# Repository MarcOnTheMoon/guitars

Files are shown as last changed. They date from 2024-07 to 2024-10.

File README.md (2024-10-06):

# Hexaphonic Guitar and Signal Analysis

> [!IMPORTANT]
> This repository is __work-in-progress__ of student theses.<br>
> It is subject to change, __not__ a reviewed publication of final results.

## What's it about?
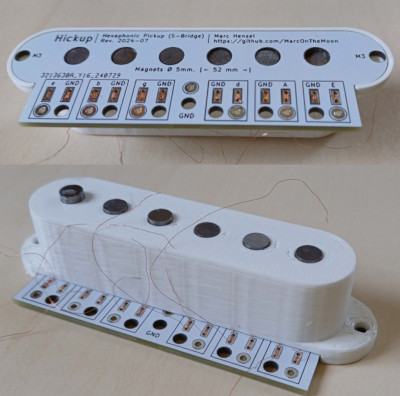
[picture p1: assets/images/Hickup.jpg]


Pickups of electric guitars typically consist of a single coil that translates oscillating movements of the strings into voltage. One electrical signal for all simultaneously played tones results. In contrast, some types of __hexaphonic pickups__ have a dedicated coil for each of the guitar's strings. Consequently, when applying pitch detection methods, one can identify which tone is played and on _which string_ it is played. Pretty cool, isn't it?

But why do we want to have a single signal for each string? Well, there are several advantages in that. Splitting the single polyphonic signal of a common pickup into six monophonic signals of a hexaphonic pickup simplifies pitch detection. So far, so boring. However, it is also the first step to automatically generate so-called tab notation while playing.

In this context, we did a first Master thesis with the objective to create a basic audio processing chain consisting of building our own hexaphonic pickup, pitch detection, and conversion into the MIDI file format. While being successful, there were too many aspects to cover, hence, the thesis could only be a proof of concept. Now comes the long and hard work of doing things "right".

Feel free to join us on this journey ... starting with the pickup. (What else?)
<br clear=all>

## Hexaphonic pickup

> [!NOTE]
> These days (October 2024) I build the next version of a largely improved pickup.<br>
> A detailed report on the design and production is in preparation and will follow soon.

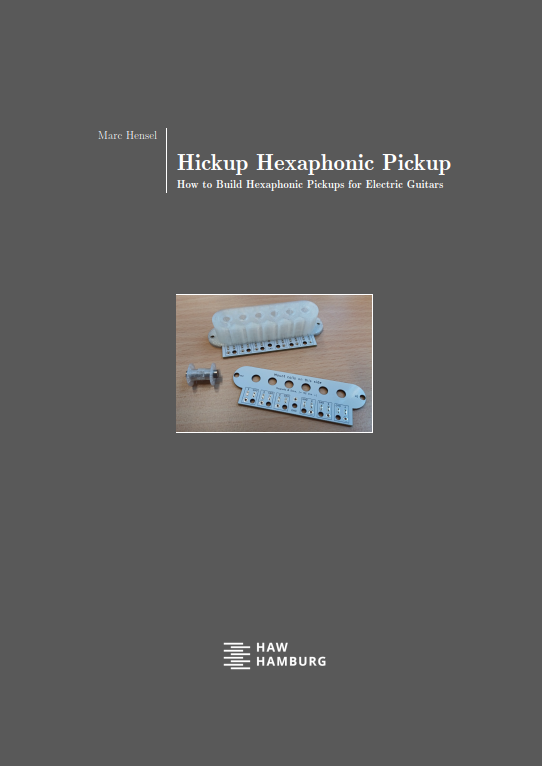
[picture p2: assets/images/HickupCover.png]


The thesis succeeded in building a hexaphonic pickup, however, this has been extremely cumbersome and the resulting pickup was mechanically instable. Meanwhile, I have developed a significantly better design and production process based on the valuable insights we got from the first try.

Amongst others, I have improved the housing, designed a custom PCB as mechanically and electrical stable cover, and I have developed a device controlled by a Python application for winding the coils. The pickup's dimensions correspond to single coil pickup mounted at the guitar bridge. Each of the six coils hat about 2,000 windings of copper wire (0.08 mm diameter with isolation), and an electrical resistance of about 170 Ohm. I use a 7-core XLR cable, which is split into 6 standard instrument cables in a dedicated adapter box. The cables connect to an USB audio interface.

As stated above, I am already preparing a detailed report on the design as well as the production process. Material such as 3D print files and the source code of the pickup winding device are available in this repository.
<br clear=all>

## Achievements so far
In a first Master thesis, Fiona Vogel managed to record samples with her own hexaphonic pickup, apply pitch detection based on the YIN algorithm, and write the result as multi-track MIDI file. Since then, the improved design of the pickup has made significant progress.

- [X] _Hardware_: design of a hexaphonic pickup (including coil winding machine, 3D prints, and PCB)
- [X] _Signal chain_: simple chain from hexaphonic guitar to signal analysis in a laptop
- [X] _Pitch detection_: proof of concept for MIDI conversion of guitar signals

## Next steps
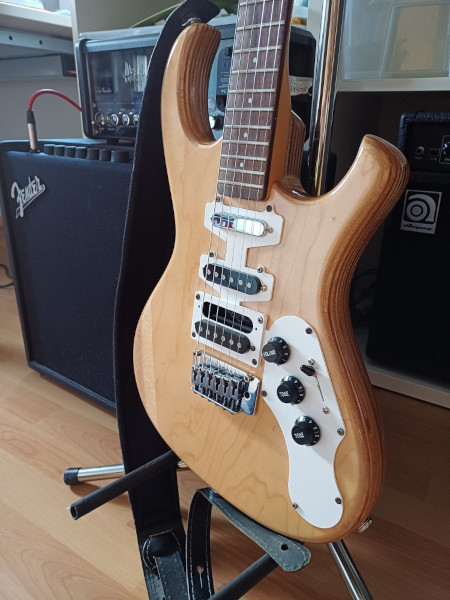
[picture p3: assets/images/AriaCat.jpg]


With our own hexaphonic pickups available, we have a good foundation for lots and lots of ideas to work on in detail. The next step is to finalize two pickups and mount these in our guitars. Future student topics include, in particular, audio signal analysis using neural networks and signal processing methods, transcription to tab notation, MIDI guitar, and live playing with low latency.

In case you are interested, I have a simple guitar from university available for my students and a private guitar for myself. I wouldn't replace any pickup of my beloved Fender Telecaster, however, I have completely renovated my old Aria Pro II Cat Series that I played in my prior life as musician. I have removed the varnish by hand (think twice before you do that!), applied transparent varnish, replaced all electric components, replaced the pickguard by own 3D-printed parts, and such. Most important, I have freed up the Humbucker slot at the bridge, which gives me plenty of space for our custom pickups.
<br clear=all>

## Uploaded material
- [X] Reports (Building the pickup, [Thesis poster](docs/reports))
- [X] Pickup housing and coils ([3D print files](hexaphonic_pickup/hardware/3d_print_files/pickup))
- [X] Coil winding device ([3D print files](hexaphonic_pickup/hardware/3d_print_files/winder), [source code](hexaphonic_pickup/src/winder))

## Contributors
The activities done so far and hopefully still to come are collaborations of myself and my magnificent students of our [Department at HAW Hamburg](https://www.haw-hamburg.de/hochschule/technik-und-informatik/departments/informations-und-elektrotechnik/studium/studiengaenge/):

- Marc Hensel (design of hexaphonic pickup and coil winder)
- Fiona Vogel (theses: hexaphonic guitar, MIDI)

## Supporters
My deepest thanks go to [No.1 Guitar Center, Hamburg](https://www.no1-guitars.de/). Sharing the same passion for music, they did not hesitate to support our work not only by kind words, but also by providing an USB audio interface offering inputs to the six coils of our hexaphonic pickups. Without this valuable support, we could not have done our work as intended.

## Contact
[Marc Hensel](http://www.haw-hamburg.de/marc-hensel), University of Applied Sciences Hamburg (HAW Hamburg)

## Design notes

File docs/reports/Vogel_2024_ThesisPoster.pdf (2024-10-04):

## Bau eines hexaphonischen Tonabnehmers und Konvertierung analoger Töne von E-Gitarren in das MIDI-Format

### Masterarbeit Fiona Vogel Prof. Dr.-Ing. Marc Hensel und Prof. Dr.-Ing. Sönke Appel

Hochschule fur Angewandte Wissenschaften Hamburg ¨ | · Fachhochschule Westkuste ¨

Tonabnehmer elektrischer Gitarren bestehen aus einer einzelnen Spule, welche Schwingungen der Saiten in einem Magnetfeld mittels Induktion in Spannung wandelt. Es resultiert ein gemeinsames elektrisches Signal fu¨r alle zeitgleich gespielten Töne. Hexaphonische Tonabnehmer nehmen hingegen jede Saite mit einer eigenen Spule ab. Durch Methoden der Tonhöhenerkennung können daher die gespielten Töne sowohl bestimmt als auch den entsprechenden Saiten zugeordnet werden. Die Aufteilung des polyphonen in sechs monophone Signale vereinfacht die Analyse und ist zugleich eine Vorbedingung zur automatischen Notentranskription in sogenannte Tabulatur.
Ziel dieser Arbeit ist eine erste Verarbeitungskette bestehend aus einem eigenen Tonabnehmer, Analyse der gespielten Tonhöhen und Konvertierung in das in der Musik verbreitete MIDI-Format (Abb. 1). Nachfolgend wird zudem der Stand der weiteren Entwicklung dargestellt sowie ein Ausblick auf mögliche weitere Abschlussarbeiten gegeben.

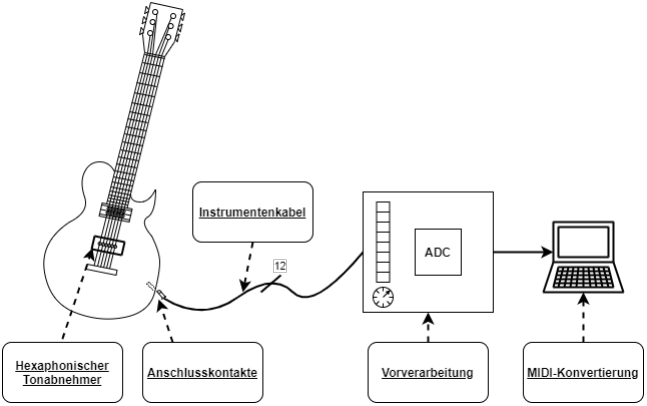
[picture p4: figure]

Abbildung 1: Verarbeitungskette

Hexaphonischer Tonabnehmer

Abbildung 2

Fu¨r den Tonabnehmer wurde ein Gehäuse mit sechs Aussparungen fu¨r Spulen modelliert und in 3D-Druck gefertigt. Die Spulen wurden aus 0,08 mm dickem Kupferlackdraht um auf einem Schrittmotor stehende Magneten gewickelt, mit Wachs im Gehäuse eingegossen und u¨ber eine Lochrasterplatine elektrisch verbunden. Nach Montage in der Gitarre wurden die Saiten u¨ber eigene Eingänge eines Audio-Interface zur Weiterverarbeitung im Laptop aufgenommen.

Analyse der Tonhöhen und MIDI-Konvertierung

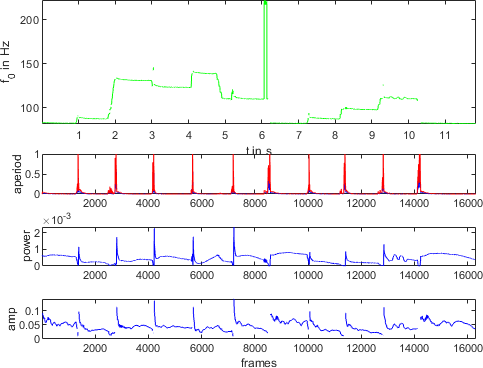
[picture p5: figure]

Abbildung 3: Tonhöhen-Analyse

Zur Bestimmung der Tonhöhen
und Konvertierung in MIDI wurden die mehrkanaligen Aufnahmen zunächst in Audio-Dateien gespeichert. Die anschließende Verarbeitung wurde in Octave umgesetzt. Sie besteht aus der unabhängigen Analyse der Tonspuren aller Saiten
auf Basis des YIN-Algorithmus sowie der Speicherung der erkannten
Töne in einer MIDI-Datei mit jeweils eigener Tonspur pro Saite.

Verbesserter Tonabnehmer (M. Hensel)

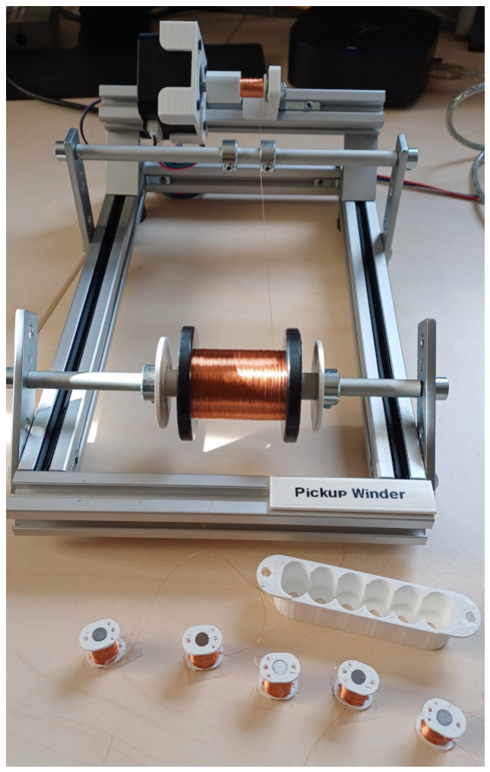
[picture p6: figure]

Abbildung 4: Spulen

Die Fertigung des Tonabnehmers hat sich als ausgesprochen muḧsam, das Resultat als mechanisch instabil erwiesen. Daher wurden inzwischen sowohl das Design als auch der Fertigungsprozess unter Beru¨cksichtigung der gewonnenen Erkenntnisse erheblich verbessert.
Unter anderem wurde das Gehäuse u¨berarbeitet, ein u¨ber eine Python-Anwendung gesteuertes Gerät zum Wickeln der Spulen sowie eine Platine als elektrisch und mechanisch stabiler Abschluss des Gehäuses entwickelt. Die Abmessungen der gefertigten Tonabnehmer entsprechen einem Single
Coil-Format in Bridge-Position. Die Spulen
enthalten jeweils etwa 2.000 Windungen und besitzen einen elektrischen Widerstand von etwa 170 Ω. Der Anschluss an die Gitarre erfolgt u¨ber ein 7-poliges XLR-Kabel, welches vor dem Audio-Interface u¨ber eine Adapter-Box auf sechs Instrumentenkabel aufgeteilt wird.

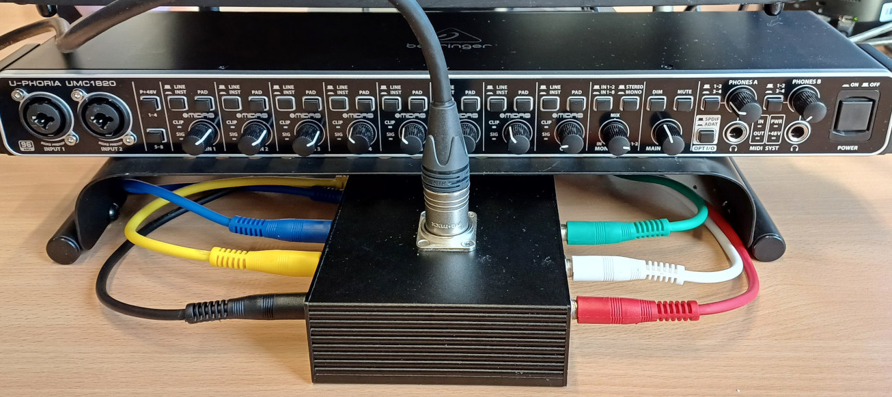
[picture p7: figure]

(a) Tonabnehmer | (b) Adapter-Box

Abbildung 5: Verbesserter Tonabnehmer und Adapter-Box

Themen fur weitere Arbeiten ¨

Potenzielle Folgearbeiten in der Audiotechnik beinhalten beispielsweise: Ton-Analyse mittels neuronaler Netze
Ton-Analyse mittels Methoden der Signalverarbeitung
Transkription in Tabulatur und weitere Anwendungen
Live-Spiel mit geringer Latenz
Entwicklung eines USB-Audio-Interfaces (Hard- und Software)

Offentliche Dateien im Internet ¨

3D-Druckdateien, Quelltexte usw. werden nach und nach auf der verlinkten Seite öffentlich zur Verfu¨gung gestellt.

Förderer

Wir danken No.1 Guitar Center GmbH, Hamburg, fu¨r das zur Verfu¨gung gestellte Audio-Interface und die damit verbundene Unterstuẗzung unserer Arbeit.

Stand: 30.09.2024

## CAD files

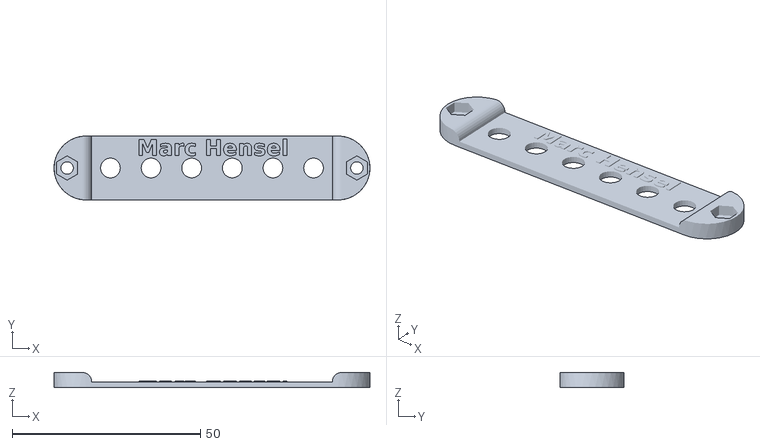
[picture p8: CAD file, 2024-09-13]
hexaphonic_pickup/hardware/3d_print_files/pickup/height 18 mm/HexPickup_Housing_Bottom.stl
84.0 x 17.0 x 4.00

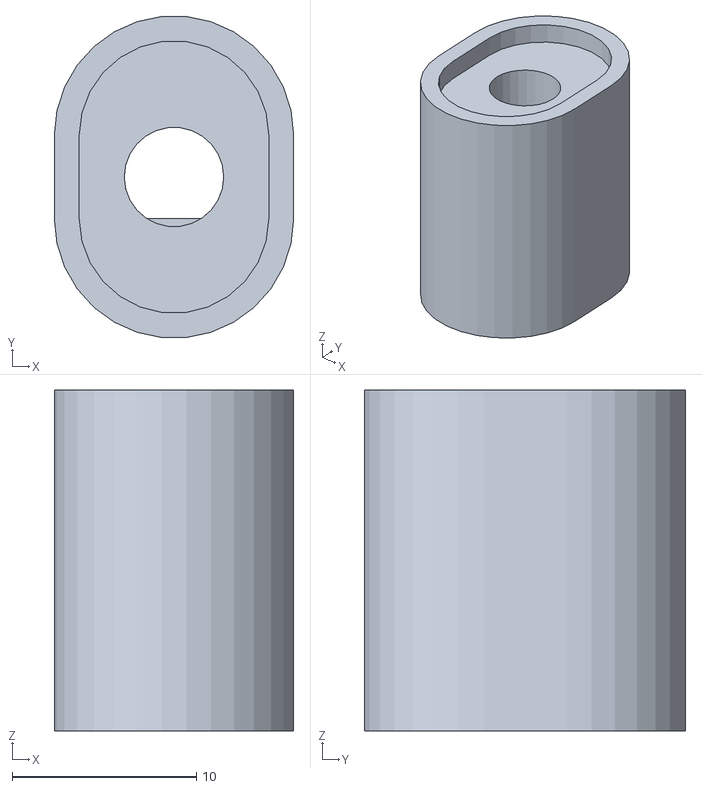
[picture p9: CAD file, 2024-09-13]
hexaphonic_pickup/hardware/3d_print_files/winder/CoilHolder-MotorTip-18.5mm-5mm.stl
13.0 x 17.4 x 18.5

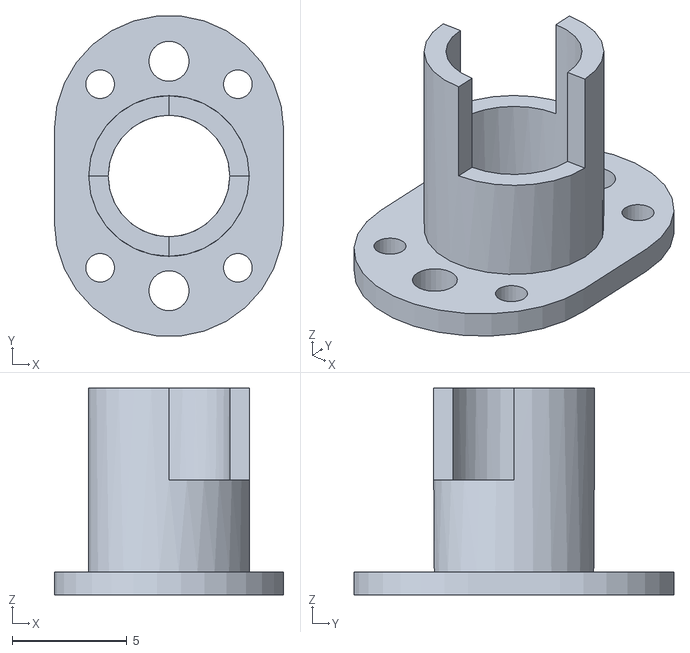
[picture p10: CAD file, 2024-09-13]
hexaphonic_pickup/hardware/3d_print_files/pickup/height 18 mm/HexPickup_Coil-14x5mm.stl
10.0 x 13.9 x 9.00

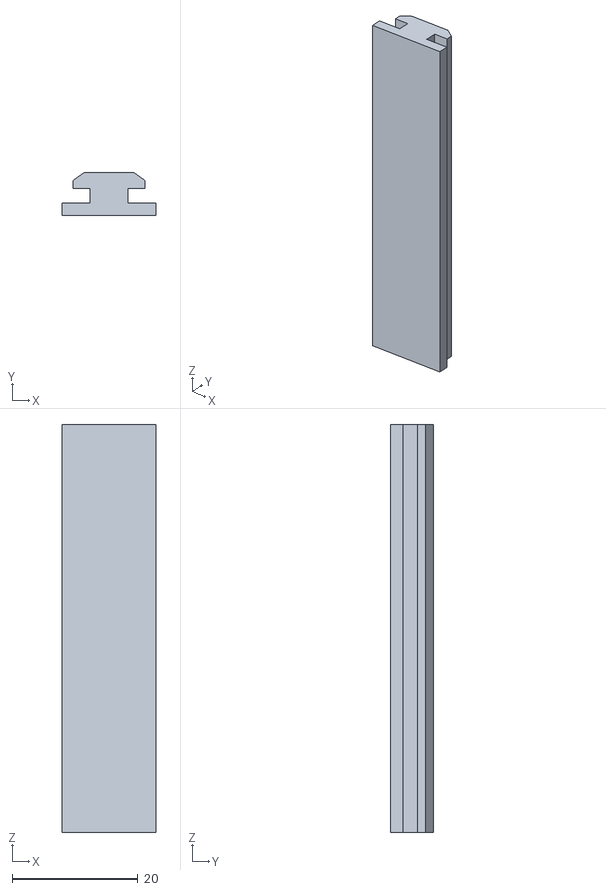
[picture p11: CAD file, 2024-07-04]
hexaphonic_pickup/hardware/3d_print_files/winder/Profile-20x20_Label-65x15mm.stl
15.0 x 6.80 x 65.0

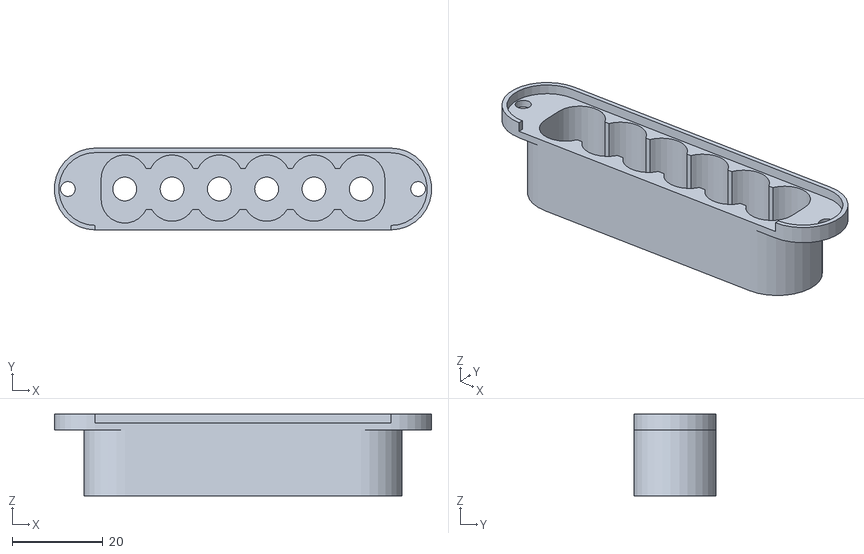
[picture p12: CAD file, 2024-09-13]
hexaphonic_pickup/hardware/3d_print_files/pickup/height 18 mm/HexPickup_Housing-70x18x18mm.stl
82.9 x 18.0 x 18.0

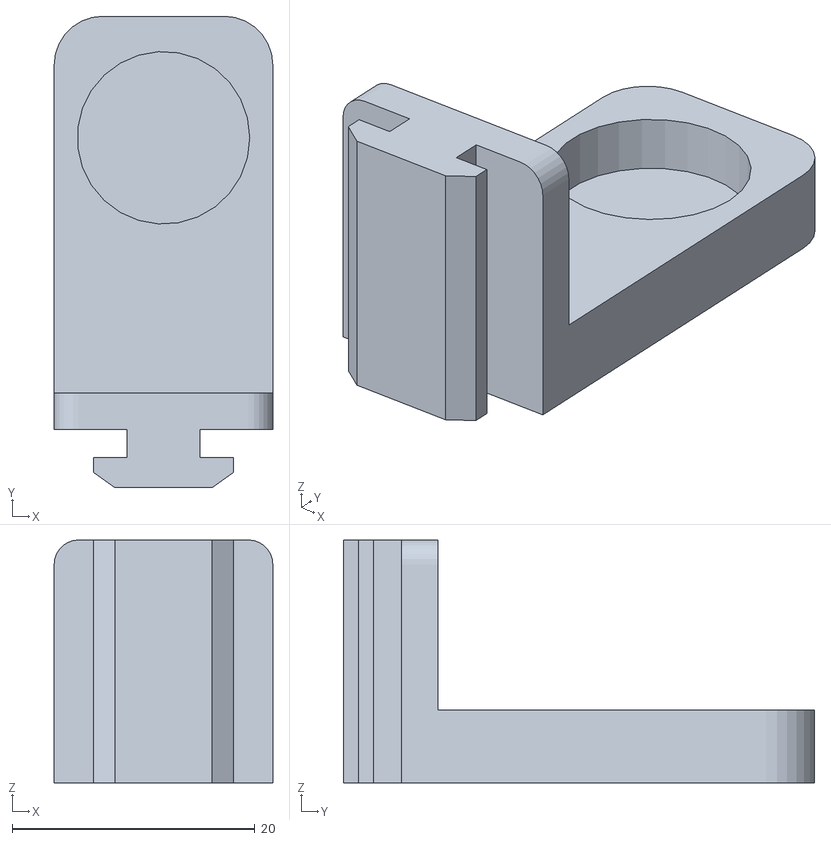
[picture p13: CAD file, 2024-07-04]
hexaphonic_pickup/hardware/3d_print_files/winder/CoilHolder-BallBearing-14x4mm.stl
18.0 x 38.8 x 20.0

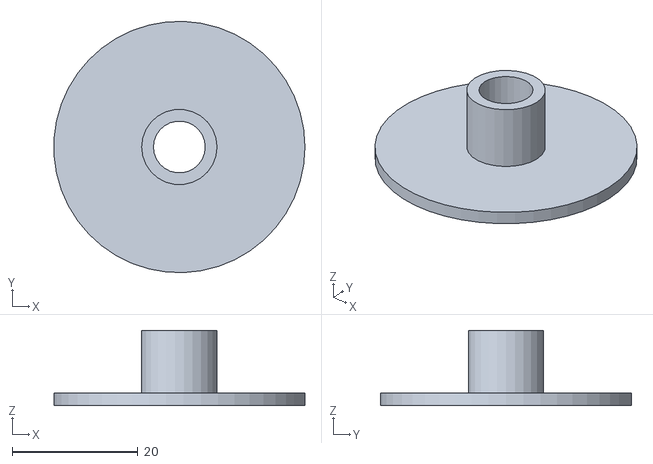
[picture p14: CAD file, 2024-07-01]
hexaphonic_pickup/hardware/3d_print_files/winder/SpoolGuidance-40mm-8mm.stl
40.0 x 40.0 x 12.0

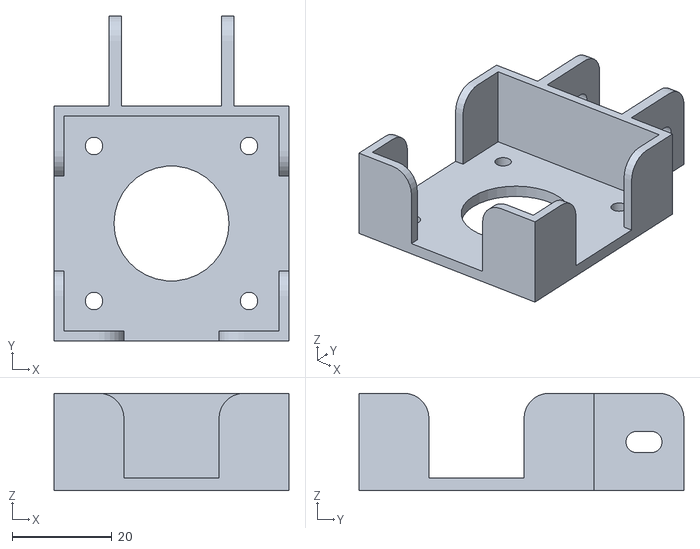
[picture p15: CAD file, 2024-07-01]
hexaphonic_pickup/hardware/3d_print_files/winder/Nema17_OnProfileMount-M4.stl
47.0 x 65.0 x 19.5

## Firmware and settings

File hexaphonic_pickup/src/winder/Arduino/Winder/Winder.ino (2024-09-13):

/*****************************************************************************************************
 * Hexaphonic pickup winder machine
 *****************************************************************************************************
 * Author: Marc Hensel, http://www.haw-hamburg.de/marc-hensel
 * Project: https://github.com/MarcOnTheMoon/guitars
 * Copyright: 2024, Marc Hensel
 * Version: 2024.09.13
 * License: CC BY-NC-SA 4.0, see https://creativecommons.org/licenses/by-nc-sa/4.0/deed.en
 *****************************************************************************************************
 * Board:
 * - Arduino Uno R3
 * 
 * Modules:
 * - None
 *****************************************************************************************************/

#include "SerialCom.h"
#include "StepperMotor.h"

/*****************************************************************************************************
 * Constants
 *****************************************************************************************************/

// Stepper motor
#define STEPPER_ENA_PIN 2
#define STEPPER_DIR_PIN 3
#define STEPPER_PUL_PIN 4
#define STEPS_PER_REVOLUTION 200  // 360° / (1.8° per step) = 200 steps

// Commands in communication with Python script
#define ENABLE_STEPPER        'E'   // Set "Enable" of motor driver to hight
#define DISABLE_STEPPER       'e'   // Set "Enable" of motor driver to low
#define DIR_CLOCKWISE         'D'   // Set "Direction" of motor driver to clockwise
#define DIR_COUNTER_CLOCKWISE 'd'   // Set "Direction" of motor driver to counter-clockwise
#define SET_SPEED_RPS         'S'   // Set motor speed (rotations per second send as next unsigned char)
#define GET_REV_COUNT         'C'   // Get count of full revolutions the motor has moved
#define RESET_REV_COUNT       'R'   // Reset counter of full revolutions the motor has moved
#define SEND_OK               '>'   // Request acqknowledge

/*****************************************************************************************************
 * Global variables
 *****************************************************************************************************/

// Serial communication (e.g., with Python script on connected Laptop)
SerialCom serialCom(Serial);

// Stepper motor (set to "not enabled" in driver's constructor)
StepperMotor motor(STEPPER_ENA_PIN, STEPPER_DIR_PIN, STEPPER_PUL_PIN, STEPS_PER_REVOLUTION);
unsigned long stepCount = 0;

/*****************************************************************************************************
 * Standard methods
 *****************************************************************************************************/

/**! Initialize program.
 * 
 * - The stepper motor is initialized with status "not enabled" as global variable.
 * - Serial communication using Arduino's "Serial" object is done using the global variable "serialCom".
 */
void setup() {
  // USB connection to Python script
  Serial.begin(38400);       // Make sure baud rate matches Python script
}

/* --------------------------------------------------------------------------------------------------*/

/**! Main loop. */
void loop() {
  // Receive and process commands
  while (serialCom.hasNext()) {
    processCommand(serialCom.getNext());
  }

  // Move stepper motor
  if (motor.getEnabled())
    stepCount += motor.moveSteps(10);
}

/*****************************************************************************************************
 * Receive and process commands
 *****************************************************************************************************/

/**! Process commands received via "serialCom".
 * 
 * @param command [in] Command (see Commands.h for mapping)
 */
void processCommand(char command) {
  switch (command) {
    // Get or restet count of full revolutions the motor has done
    case GET_REV_COUNT:
      Serial.println((unsigned long)(stepCount / STEPS_PER_REVOLUTION));
      break;
    case RESET_REV_COUNT:
      stepCount = 0;
      break;

    // Set enabled pin of stepper driver
    case ENABLE_STEPPER:
      motor.setEnabled(true);
      break;
    case DISABLE_STEPPER:
      motor.setEnabled(false);
      break;

    // Set stepper turning direction
    case DIR_CLOCKWISE:
      motor.setDirection(MotorDirection::CLOCKWISE);
      break;
    case DIR_COUNTER_CLOCKWISE:
      motor.setDirection(MotorDirection::COUNTER_CLOCKWISE);
      break;
      
    // Set stepper motor speed
    case SET_SPEED_RPS:
      motor.setTargetSpeed(serialReceiveNextValue());
      break;

    // Send acqknowledge
    case SEND_OK:
      Serial.println("ok");
      break;
  }
}

/* --------------------------------------------------------------------------------------------------*/

/**! Wait for and get next value sent over serial communication.
 * 
 * @return Next received value
 */
int serialReceiveNextValue(void) {
  // Wait for next sent byte
  while (serialCom.hasNext() == false) {
    // NOP
  }

  return (int)serialCom.getNext();
}

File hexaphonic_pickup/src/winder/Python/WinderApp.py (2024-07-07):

"""
Control app for a hexaphonic pickup winder.

@author: Marc Hensel
@contact: http://www.haw-hamburg.de/marc-hensel
@copyright: 2024
@version: 2024.07.07
@license: CC BY-NC-SA 4.0, see https://creativecommons.org/licenses/by-nc-sa/4.0/deed.en
"""
import time
import threading
from ArduinoCOM import ArduinoCOM
from WinderGUI import WinderGUI

class WinderApp():

    # =========================================================================
    # ========== Class constants ==============================================
    # =========================================================================

    # Command chars expected by the Arduino
    _commands = {
        'enableMotor':          'E',    # 'Enable' signal high
        'disableMotor':         'e',    # 'Enable' signal low
        'dirClockwise':         'D',    # Direction clockwise
        'dirCounterClockwise':  'd',    # Direction counter-clockwise
        'setSpeedRevsPerSec':   'S',
        'getRevCount':          'C',
        'resetRevCounter':      'R',
        'sendOk':               '>'
    }

    # =========================================================================
    # ========== Constructor ==================================================
    # =========================================================================

    def __init__(self, serialCOM=None):
        """
        Constructor.
        
        The contructor tries to connect to an Arduino using serial COM ports.
        If connection succeeds, it generates and runs the GUI.
        
        Parameters
        ----------
        serialCOM : int, optional
            Serial port Arduino is connected to (e.g., '3' for 'COM3').
            Tries to connect to ports 0 to 15, if argument is None. (Default: None)

        Returns
        -------
        None.

        """
        # Connect to Arduino (will reset Arduino => Runs setup())
        self.__threadLock = threading.Lock()
        self.__arduino = ArduinoCOM(serialCOM=serialCOM, baudRate=38_400)

        # Create and start GUI
        self.__gui = WinderGUI(parentApp=self)

    # =========================================================================
    # ========== Serial connection ============================================
    # =========================================================================

    def close(self, waitTimeSec=2.0):
        """
        Requests Arduino to stop and disable stepper motor and closes serial connection.

        Parameters
        ----------
        waitTimeSec : float
            Delay before stopping and disabling stepper [s] (Default: 2.0)

        Returns
        -------
        None.

        """
        time.sleep(waitTimeSec)
        print('\nClosing connection:')
        self.setSpeed(revsPerSec=0)
        self.enableMotor(False)
        time.sleep(1.0)             # Wait for Arduino to read buffer
        self.__arduino.close()

    # -------------------------------------------------------------------------

    def __sendWithReply(self, command, isRequestAck=True):
        """
        Send command to Arduino requesting and waiting for reply.

        Parameters
        ----------
        command : string
            Command string to send (typically chars from dictionary _command).

        Returns
        -------
        string
            Reply send by the Arduino (typically 'ok' when requesting ACK).

        """
        # Send command (and request for acknowledgement)
        if isRequestAck == True:
            self.__arduino.writeString(command + self._commands['sendOk'])
        else:
            self.__arduino.writeString(command)
            
        # Receive and return reply
        return self.__arduino.readLine()

    # =========================================================================
    # ========== Motor control ================================================
    # =========================================================================

    def enableMotor(self, isEnabled):
        """
        Enable or disable stepper motor.
        
        If the motor is enabled, current is flowing through it and it actively
        holds its position. When disabled, one can easily move the motor by
        hand.

        Parameters
        ----------
        isEnabled : boolean
            Enable stepper if True, else disable stepper.

        Returns
        -------
        None.

        """
        self.__threadLock.acquire()

        # Determine command
        if isEnabled:
            print('Enable motor', end=' ')
            command = self._commands['enableMotor']
        else:
            print('Disable motor', end=' ')
            command = self._commands['disableMotor']

        # Send command and print reply
        reply = self.__sendWithReply(command)
        print('... ' + reply)            
        self.__threadLock.release()

    # -------------------------------------------------------------------------

    def setDirection(self, isClockwise):
        """
        Set the turning direction of the stepper motor.

        Parameters
        ----------
        isClockwise : boolean
            Turn steppr clockwise if True, else counter-clockwise.

        Returns
        -------
        None.

        """
        self.__threadLock.acquire()

        # Determine command
        if isClockwise:
            print('Turn clockwise', end=' ')
            command = self._commands['dirClockwise']
        else:
            print('Turn counter-clockwise', end=' ')
            command = self._commands['dirCounterClockwise']

        # Send command and print reply
        reply = self.__sendWithReply(command)
        print('... ' + reply)            
        self.__threadLock.release()

    # -------------------------------------------------------------------------
    
    def setSpeed(self, revsPerSec):
        """ Set stepper motor speed.
        
        Parameters
        ----------
        revsPerSec : int
            Motor speed [revolutions/sec].

        Returns
        -------
        None.

        """
        self.__threadLock.acquire()

        # Command + value
        print('Set speed [rps]: {}'.format(revsPerSec), end=' ')
        command = self._commands['setSpeedRevsPerSec']
        command += chr(revsPerSec)

        # Send command and print reply
        reply = self.__sendWithReply(command)
        print('... ' + reply)
        self.__threadLock.release()

    # =========================================================================
    # ========== Revolution counter ===========================================
    # =========================================================================

    def getRevCount(self):
        """ Get count of motor full revolutions from Arduino.
        
        Warning: Querying the rev count leads to a small pause in turning the
        stepper motor at the Arduino side. To run the stepper smoothly, do not
        use the query.
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

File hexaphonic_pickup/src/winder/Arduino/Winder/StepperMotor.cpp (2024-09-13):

/*****************************************************************************************************
 * Control stepper motor
 *****************************************************************************************************
 * Author: Marc Hensel, http://www.haw-hamburg.de/marc-hensel
 * Project: https://github.com/MarcOnTheMoon/guitars
 * Copyright: 2024, Marc Hensel
 * Version: 2024.09.13
 * License: CC BY-NC-SA 4.0, see https://creativecommons.org/licenses/by-nc-sa/4.0/deed.en
 *****************************************************************************************************/

#include "StepperMotor.h"
#include <Arduino.h>

/*****************************************************************************************************
 * Constructor
 *****************************************************************************************************/

/**! Initialize object.
 * 
 * @param enablePin [in] Arduino port connecting to motor driver's "Enable"
 * @param dirPin [in] Arduino port connecting to motor driver's "Direction"
 * @param pulsePin [in] Arduino port connecting to motor driver's "Pulse"
 */
StepperMotor::StepperMotor(int enablePin, int dirPin, int pulsePin,int stepsPerRevolution)
  : driver(enablePin, dirPin, pulsePin), STEPS_PER_REV(stepsPerRevolution) {
}

/*****************************************************************************************************
 * Getter
 *****************************************************************************************************/

/**! Get status of driver's enable port.
 * 
 * @return True if motor is enabled, else false.
 */
bool StepperMotor::getEnabled() {
  return isEnabled;
}

/*****************************************************************************************************
 * Setter
 *****************************************************************************************************/

/**! Set driver's enable port.
 * 
 * @param isEnabled [in] Set enable port to HIGH if true, else LOW
 */
void StepperMotor::setEnabled(bool isEnabled) {
  this->isEnabled = isEnabled;
  driver.setEnabled(isEnabled);
}

/* --------------------------------------------------------------------------------------------------*/

/**! Set driver's direction of motor rotation.
 * 
 * @param dir [in] Set rotation to CLOCKWISE or COUNTER_CLOCKWISE
 */
void StepperMotor::setDirection(MotorDirection dir) {
  driver.setDirection(dir);
}

/* --------------------------------------------------------------------------------------------------*/

/**! Set the target speed.
 * 
 * @param targetRevsPerSec [in] Target speed in revolutions per second [rps]
 */
void StepperMotor::setTargetSpeed(double targetRevsPerSec) {
  targetSpeedRevsPerSec = targetRevsPerSec;
}

/*****************************************************************************************************
 * Move motor(s)
 *****************************************************************************************************/

/**! Move by a specific number of steps.
 * 
 * @param numberSteps [in] Number of steps to move
 * 
 * @return Number of steps moved (being 0 if speed is 0)
 */
int StepperMotor::moveSteps(int numberSteps) {
  int stepsMoved = 0;

  // Adapt speed (accelerate toward target speed)
  adaptSpeed();

  // Move steps (if speed is not zero)
  if (speedRevsPerSec > 0.5) {
    unsigned long stepsPerSec = speedRevsPerSec * STEPS_PER_REV;
    unsigned long durationMicros =  1000000 / stepsPerSec;
  
    for (int i = 0; i < numberSteps; i++)
      driver.moveStep(durationMicros);
    stepsMoved = numberSteps;
  }

  return stepsMoved;
}

/* --------------------------------------------------------------------------------------------------*/

/**! Accelerate current speed toward target speed.
 */
void StepperMotor::adaptSpeed() {
  double deltaSpeed = targetSpeedRevsPerSec - speedRevsPerSec;
  
  if (abs(deltaSpeed) < 0.25) {
    speedRevsPerSec = targetSpeedRevsPerSec;
  } else {
    speedRevsPerSec += deltaSpeed / 5;
  }
}

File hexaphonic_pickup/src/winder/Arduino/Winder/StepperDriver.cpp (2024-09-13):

/*****************************************************************************************************
 * Control stepper motor driver (such as TB6600)
 *****************************************************************************************************
 * Author: Marc Hensel, http://www.haw-hamburg.de/marc-hensel
 * Project: https://github.com/MarcOnTheMoon/guitars
 * Copyright: 2024, Marc Hensel
 * Version: 2024.09.13
 * License: CC BY-NC-SA 4.0, see https://creativecommons.org/licenses/by-nc-sa/4.0/deed.en
 *****************************************************************************************************/

#include "StepperDriver.h"
#include <Arduino.h>

/*****************************************************************************************************
 * Constructor
 *****************************************************************************************************/

/**! Initialize with direction CLOCKWISE and motor disabled.
 * 
 * @param enablePin [in] Arduino port connecting to "Enable"
 * @param dirPin [in] Arduino port connecting to "Direction"
 * @param pulsePin [in] Arduino port connecting to "Pulse"
 */
StepperDriver::StepperDriver(int enablePin, int dirPin, int pulsePin) : ENABLE_PIN(enablePin), DIR_PIN(dirPin), PULSE_PIN(pulsePin) {
  // Direction and pulse
  pinMode(DIR_PIN, OUTPUT);
  pinMode(PULSE_PIN, OUTPUT);
  setDirection(MotorDirection::CLOCKWISE);
  digitalWrite(PULSE_PIN, LOW);

  // Enable (initially disabled)
  pinMode(ENABLE_PIN, OUTPUT);
  setEnabled(false);
}

/*****************************************************************************************************
 * Setter
 *****************************************************************************************************/

/**! Set enable port.
 * 
 * Assumes that the "ENA-" pin of the driver is connected to ground, hence, the arduino sets its port
 * to LOW for "enabled" and HIGH for "disabled".
 * 
 * @param isEnabled [in] Set enable port to LOW if true, else HIGH
 */
void StepperDriver::setEnabled(bool isEnabled) {
  digitalWrite(ENABLE_PIN, (isEnabled) ? LOW : HIGH);
}

/* --------------------------------------------------------------------------------------------------*/

/**! Set direction of motor rotation.
 * 
 * Assumes that the "DIR-" pin of the driver is connected to ground, hence, the arduino sets its port
 * to HIGH for clockwise and LOW for counter-clockwise rotation.
 * 
 * @param dir [in] Set rotation to CLOCKWISE or COUNTER_CLOCKWISE
 */
void StepperDriver::setDirection(MotorDirection dir) {
  digitalWrite(DIR_PIN, (dir == MotorDirection::CLOCKWISE) ? HIGH : LOW);
}

/*****************************************************************************************************
 * Move
 *****************************************************************************************************/

/**! Move motor by one step.
 * 
 * Sets the step pulse to HIGH and LOW for roughly half the targeted duration (durationMicros).
 * 
 * @param durationMicros [in] Overall approximal period for a step [microsecs]
 */
void StepperDriver::moveStep(int durationMicros) {
  unsigned long stopTimeMicros = micros() + durationMicros;
  
  digitalWrite(PULSE_PIN, HIGH);
  delayMicroseconds(durationMicros / 2);
  
  digitalWrite(PULSE_PIN, LOW);
  delayMicroseconds(max(stopTimeMicros - micros(), 0));
}

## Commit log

2024-07-01 Initial commits
    [HexPickup_Coil-15x5mm.stl, HexPickup_Housing.stl, HexPickup_Winder_Guidance.stl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]
2024-07-01 Renamed print files
    [HexPickup_Winder_MotorTip.stl, HexPickup_Winder_SpoolGuidance.stl]
2024-07-04 Initial Python app, modified 3d print files
    [CoilHolder-BallBearing-14x4mm.stl, CoilHolder-MotorTip-18.5mm-5mm.stl, Profile-20x20_Label-65x15mm.stl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]
2024-07-05 Initial Arduino software for coil winder
2024-07-07 Added motor direction to pickup winder
2024-09-13 Adapted 3d print files
    [CoilHolder-BallBearing-14x4mm.stl, CoilHolder-MotorTip-18.5mm-5mm.stl, HexPickup_Coil-14x5mm.stl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]
2024-09-13 Restructured project
    [CoilHolder-BallBearing-14x4mm.stl, CoilHolder-MotorTip-18.5mm-5mm.stl, HexPickup_Coil-14x5mm.stl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]
